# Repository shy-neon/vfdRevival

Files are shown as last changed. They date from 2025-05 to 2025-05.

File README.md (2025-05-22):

# VFD-Revival

<div style="display: flex">
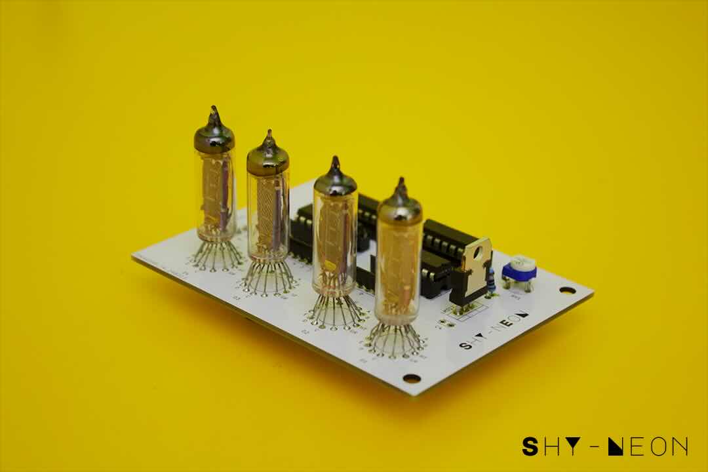
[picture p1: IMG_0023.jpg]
  
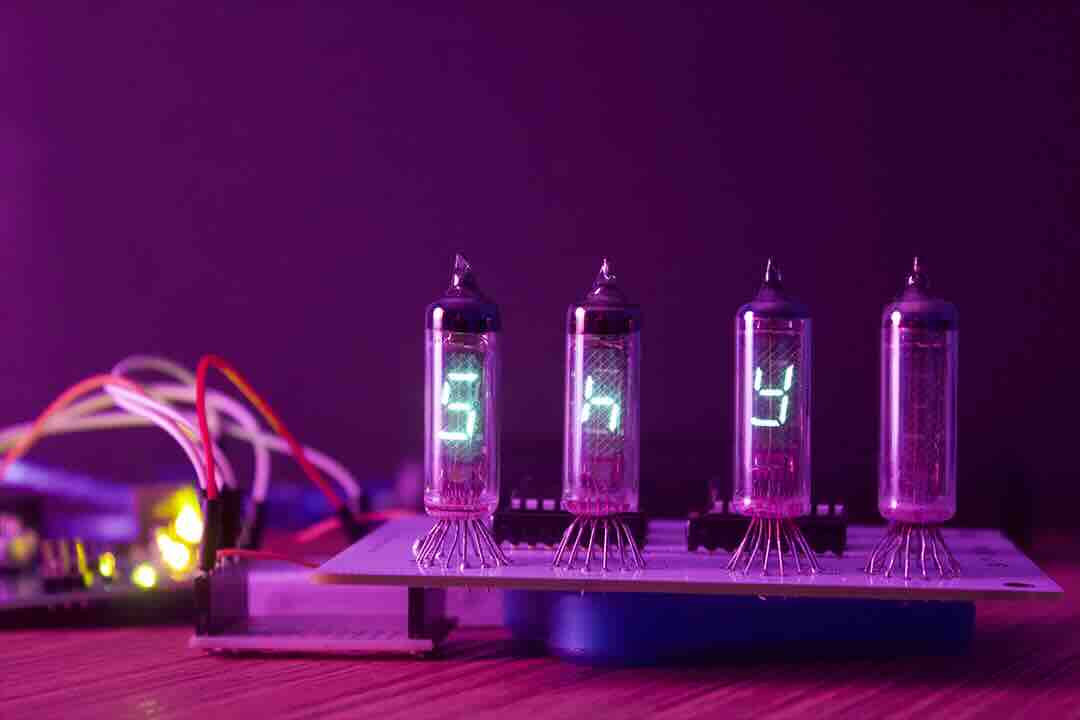
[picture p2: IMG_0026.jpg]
  
</div>
<br>
Although many ICs for driving VFD displays exist, they are generally out of production, or even out of stock. Many can be found on Ebay but usually they are very expensive and New Old Stock soviet ICs. The main goal of this project is to drive those tubes with jellybeans ICs, which can be easily sourced at reasonables proces. The repo proveides an example sketch, schematics and pcb layouts.

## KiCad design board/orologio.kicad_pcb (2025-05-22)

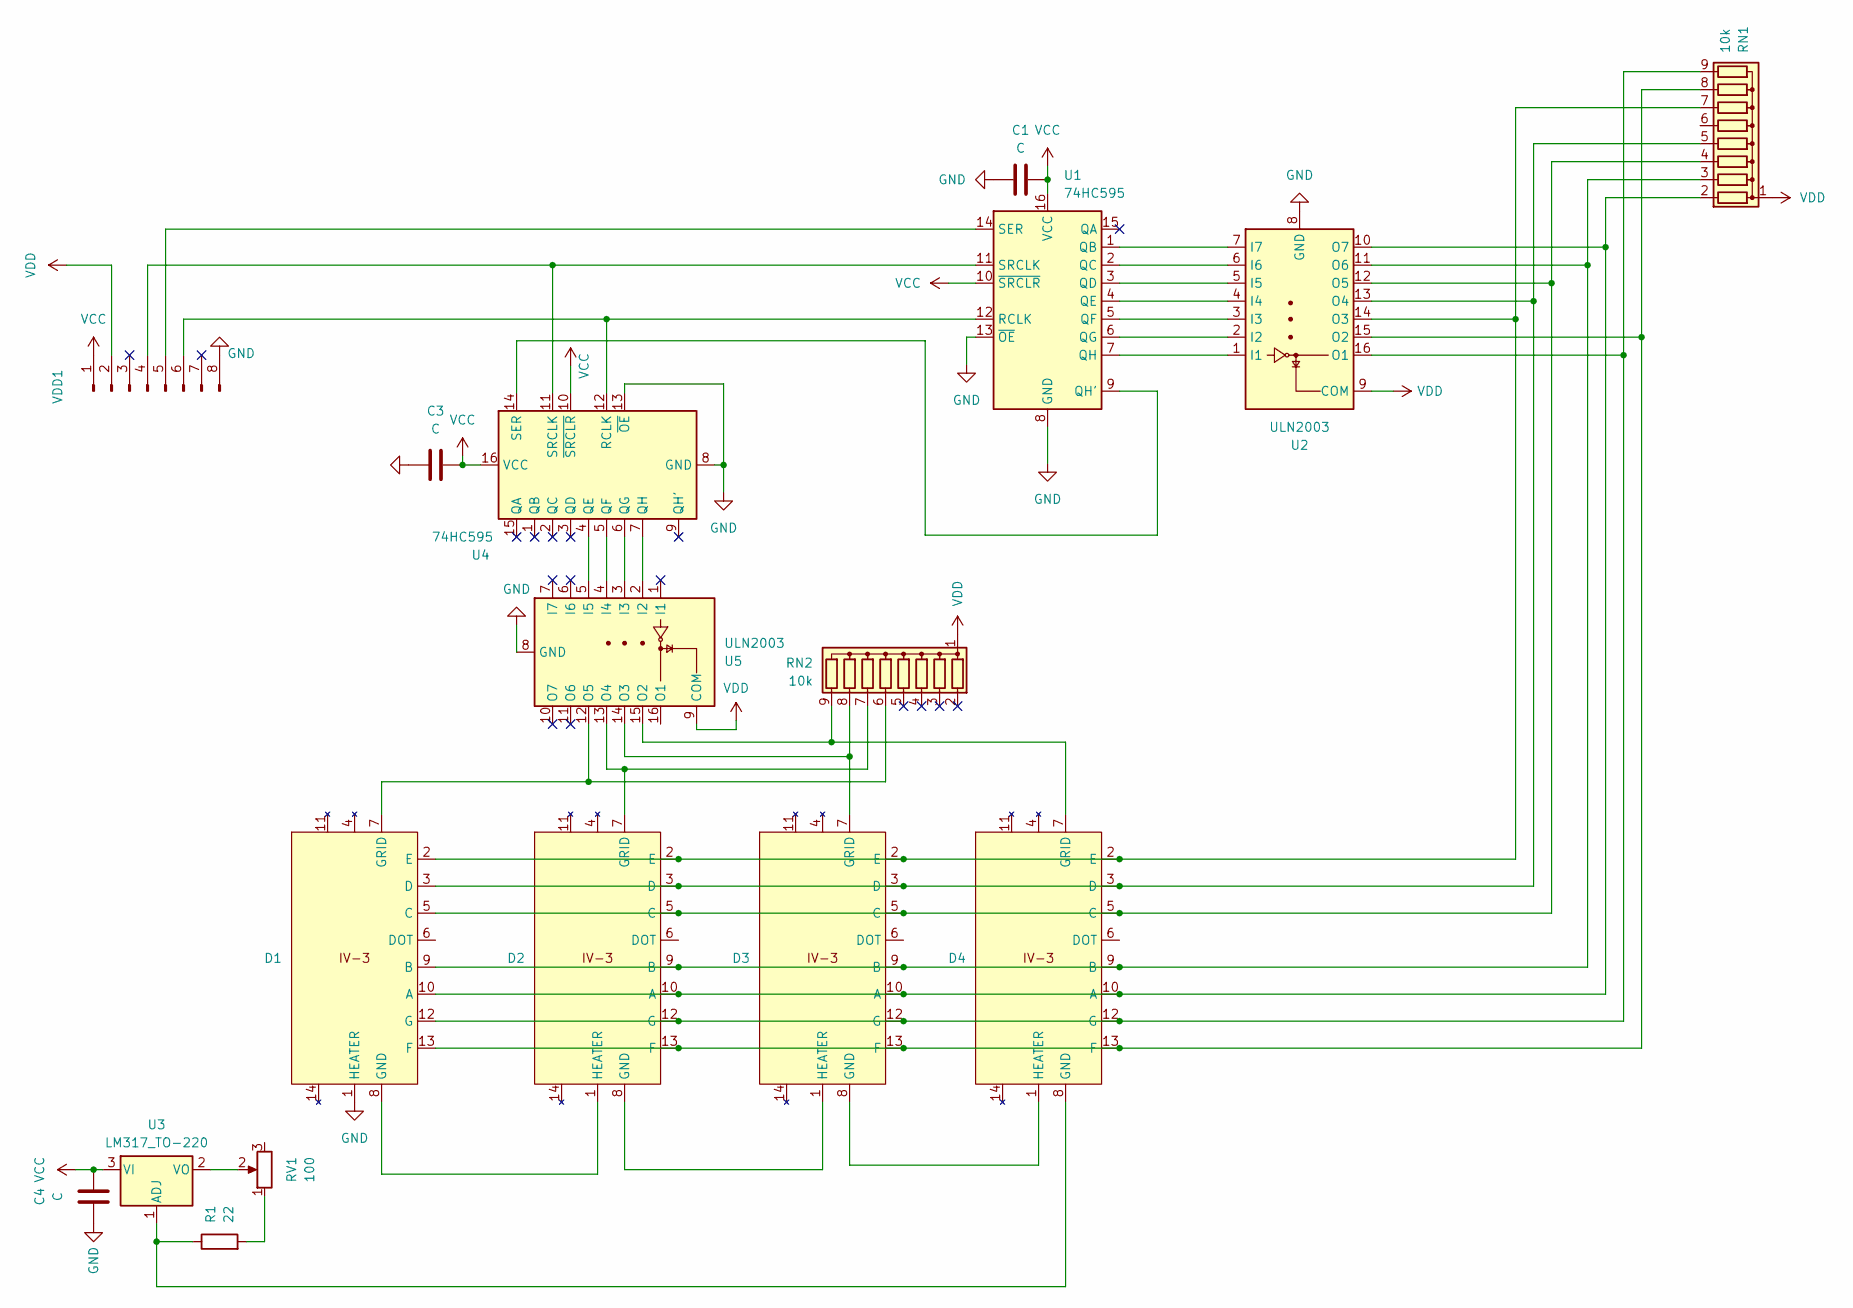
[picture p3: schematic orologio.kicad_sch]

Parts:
C1, C3, C4: C; C_Disc_D3.4mm_W2.1mm_P2.50mm
D1, D2, D3, D4: IV-3
R1: 22; R_Axial_DIN0204_L3.6mm_D1.6mm_P1.90mm_Vertical
RN1, RN2: 10k; R_Array_SIP9
RV1: 100; Potentiometer_Piher_PT-6-V_Vertical
U1, U4: 74HC595; DIP-16_W7.62mm_Socket_LongPads
U2, U5: ULN2003; DIP-16_W7.62mm_Socket_LongPads
U3: LM317_TO-220; TO-220-3_Vertical
VDD1: Conn_01x08_Pin; PinHeader_1x08_P2.54mm_Vertical

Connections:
GND: C1.1, C3.1, C4.2, D1.1 (HEATER), U1.8 (GND), U1.13 (~OE), U2.8 (GND), U4.8 (GND), U4.13 (~OE), U5.8 (GND), VDD1.8
unnamed: D1.10 (A), D2.10 (A), D3.10 (A), D4.10 (A), RN1.2 (R1), U2.10 (O7)
unnamed: D1.9 (B), D2.9 (B), D3.9 (B), D4.9 (B), RN1.3 (R2), U2.11 (O6)
unnamed: D1.5 (C), D2.5 (C), D3.5 (C), D4.5 (C), RN1.4 (R3), U2.12 (O5)
unnamed: D1.3 (D), D2.3 (D), D3.3 (D), D4.3 (D), RN1.5 (R4), U2.13 (O4)
unnamed: D1.2 (E), D2.2 (E), D3.2 (E), D4.2 (E), RN1.7 (R6), U2.14 (O3)
unnamed: D1.13 (F), D2.13 (F), D3.13 (F), D4.13 (F), RN1.8 (R7), U2.15 (O2)
unnamed: D1.12 (G), D2.12 (G), D3.12 (G), D4.12 (G), RN1.9 (R8), U2.16 (O1)
unnamed: D1.8 (GND), D2.1 (HEATER)
unnamed: D1.7 (GRID), RN2.6 (R5), U5.12 (O5)
unnamed: D2.8 (GND), D3.1 (HEATER)
unnamed: D2.7 (GRID), RN2.7 (R6), U5.13 (O4)
unnamed: D3.8 (GND), D4.1 (HEATER)
unnamed: D3.7 (GRID), RN2.8 (R7), U5.14 (O3)
unnamed: D4.8 (GND), R1.1, U3.1 (ADJ)
unnamed: D4.7 (GRID), RN2.9 (R8), U5.15 (O2)
unnamed: R1.2, RV1.1
unnamed: U1.1 (QB), U2.7 (I7)
unnamed: U1.2 (QC), U2.6 (I6)
unnamed: U1.3 (QD), U2.5 (I5)
unnamed: U1.4 (QE), U2.4 (I4)
unnamed: U1.5 (QF), U2.3 (I3)
unnamed: U1.6 (QG), U2.2 (I2)
unnamed: U1.9 (QH'), U4.14 (SER)
unnamed: U1.7 (QH), U2.1 (I1)
unnamed: U1.12 (RCLK), U4.12 (RCLK), VDD1.6
unnamed: U1.14 (SER), VDD1.5
unnamed: U1.11 (SRCLK), U4.11 (SRCLK), VDD1.4
unnamed: RV1.2, U3.2 (VO)
unnamed: U4.4 (QE), U5.5 (I5)
unnamed: U4.5 (QF), U5.4 (I4)
unnamed: U4.6 (QG), U5.3 (I3)
unnamed: U4.7 (QH), U5.2 (I2)
VCC: C1.2, C3.2, C4.1, U1.10 (~SRCLR), U1.16 (VCC), U3.3 (VI), U4.10 (~SRCLR), U4.16 (VCC), VDD1.1
VDD: RN1.1 (common), RN2.1 (common), U2.9 (COM), U5.9 (COM), VDD1.2

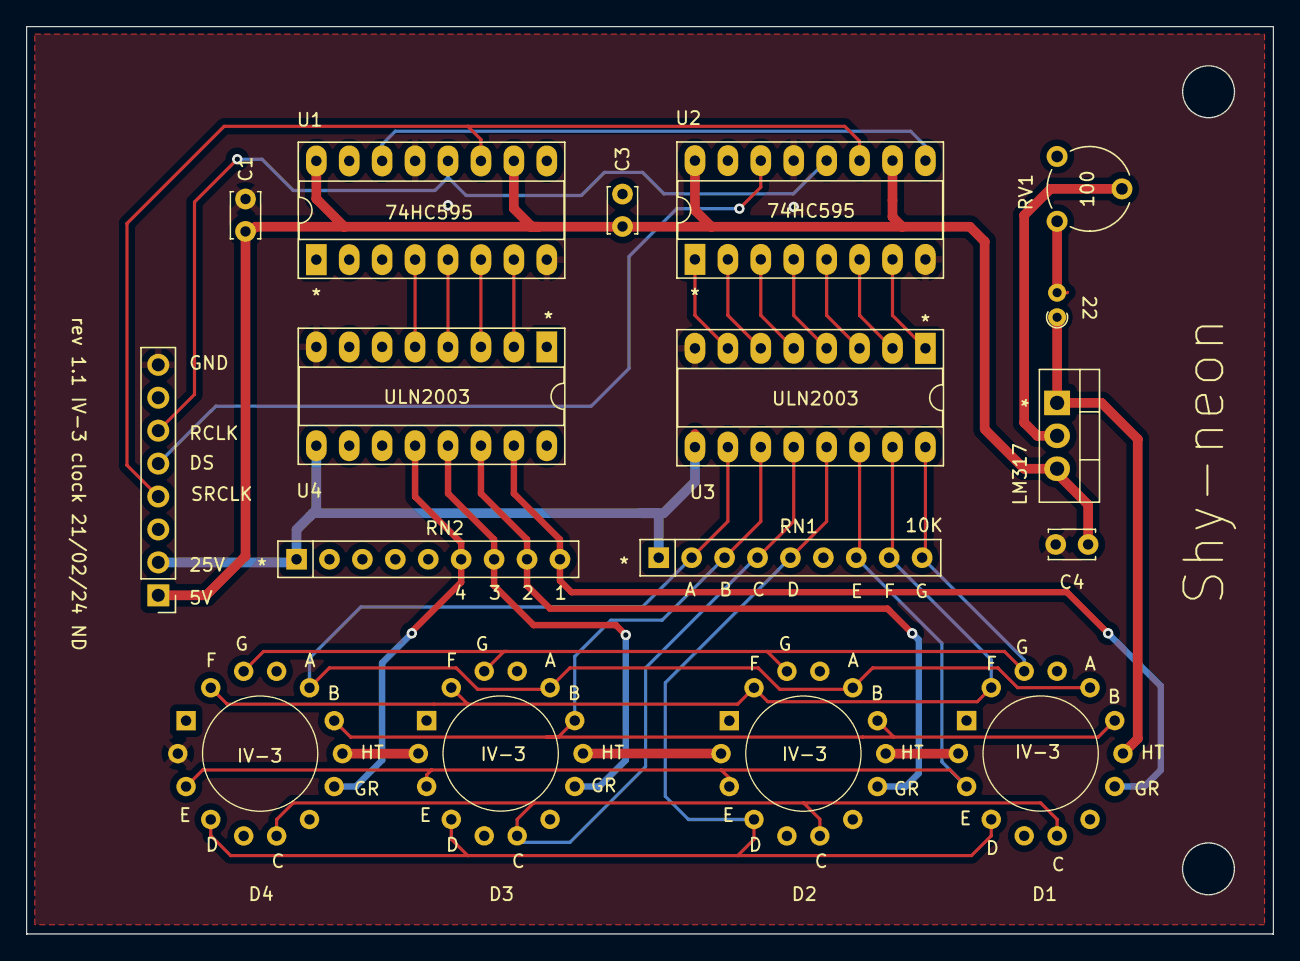
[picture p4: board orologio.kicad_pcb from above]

Board: 2 copper layers, 96.2 x 70.0 mm, 17 parts (0 on the bottom side), 35 nets.

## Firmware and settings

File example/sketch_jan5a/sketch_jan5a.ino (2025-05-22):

//**************************************************************//
//  Name    : VFD clock, Hello World
//  Author  : Nicola Di Gregorio, Shy-neon
//  Date    : 25 Mar, 2024
//  Version : 1.0
//  Notes   : Code to comunicate
//          : with the IV-3 display module
//****************************************************************
//Pin connected to RCLK of 74HC595
int latchPin = 9;
//Pin connected to SRCLK of 74HC595
int clockPin = 12;
////Pin connected to DS of 74HC595
int dataPin = 11;

#include <String.h>
#include <time.h>

void setup() {
//set pins to output so you can control the shift register
pinMode(latchPin, OUTPUT);
pinMode(clockPin, OUTPUT);
pinMode(dataPin, OUTPUT);

}

void loop() {
 printString("   shy-neon    ");
}

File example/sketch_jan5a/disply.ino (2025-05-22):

int toDigit (int number) {
  switch(number){
    case 1:
      return 207;
    case 2:
      return 146;
    case 3:
      return 134;
    case 4:
      return 204;
    case 5:
      return 164;
    case 6:
      return 160;
    case 7:
      return 143;
    case 8:
      return 128;
    case 9:
      return 132;
    case 0:
      return 129;
    case 'a':
      return 136;
    case 'b':
      return 224;
    case 'c':
      return 177;
    case 'd':
      return 194;
    case 'e':
      return 176;
    case 'f':
      return 184;
    case 'g':
      return 132;
    case 'h':
      return 232;
    case 'i':
      return 249;
    case 'l':
      return 241;
    case 'm':
      return 255;
    case 'n':
      return 234;
    case 'o':
      return 226;
    case 'p':
      return 152;
    case 's':
      return 164;
    case 't':
      return 224;
    case 'u':
      return 184;
    case 'v':
      return 193;
    case 'z':
      return 146;
    case 'y':
      return 196;
    default:
      return 255;
  }
}

void printString (char * string){
  unsigned long t, dt = 0;
  char * out;
  while(t < strlen(string)-3  ){
  print(string[3 + t], 1);
  delay(2);
  print(string[2 + t], 2);
  delay(18);
  print(string[1 + t], 3);
  delay(1);
  print(string[0 + t], 4);
  delay(1);
  
    if (millis() - dt > 500){
      t++;
      dt = millis();
    }
  }  
}

void print (int value, int display){
  int tube = 0;
  switch (display) {
    case 1:
      tube = 14;
      break;
    case 2:
      tube = 13;
      break;
    case 3:
      tube = 11;
      break;
    case 4:
      tube = 7;
      break;
  }
  digitalWrite(latchPin, LOW);
  shiftOut(dataPin, clockPin, LSBFIRST, tube);
  shiftOut(dataPin, clockPin, LSBFIRST, toDigit(value));
  digitalWrite(latchPin, HIGH);
}
